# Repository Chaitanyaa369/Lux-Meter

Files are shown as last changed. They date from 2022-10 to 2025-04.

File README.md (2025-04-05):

💡 Lux Meter with ESP8266

This project is a web-based Lux Meter built using an ESP8266 microcontroller. It measures light intensity using a light sensor and displays the data graphically in real-time through a web interface. The design includes firmware, HTML/JS/CSS for visualization, and a custom-designed PCB.

📦 Project Structure

    Lux-Meter/
    │
    ├── Lux_meter/
    |    ├── Lux_meter.ino             # Firmware for ESP8266
    |    ├── index.html                # Web interface to visualize Lux data
    |    ├── style.css                 # Styling for the web interface
    │
    ├── Lux_Meter.sch             # Schematic file (Eagle)
    ├── Lux_Meter.brd             # PCB layout file (Eagle)
    ├── LM-Top.pdf                # PCB top view
    ├── LM-Bottom.pdf             # PCB bottom view
    ├── LM-C_name_value.pdf       # Component name/value placement
    ├── LM -components.pdf        # Components and connections
    │
    └── README.md                 # This file

🧠 Features

- Real-time Lux data visualization using Highcharts

- Simple Start/Stop/Reset buttons for live data streaming

- ESP8266-hosted web server

- Minimal and responsive interface

- Custom PCB design for compact integration

🔧 Hardware Used

- ESP8266 (ESP-12E/F)

- Light sensor (LDR or BH1750)

- LM1117-3.3V voltage regulator

- Capacitors: 100nF, 470pF, 47uF

- Resistors: 12K

- USB-to-Serial interface

- Misc: Connectors, header pins

You can view the hardware setup using:

- 📄 LM -components.pdf

- 🖼️ LM-Top.pdf and LM-Bottom.pdf

- 📐 LM-C_name_value.pdf

💻 Software Used

- Arduino IDE (for programming ESP8266)

- EAGLE CAD (for PCB design)

- HTML/CSS/JavaScript + Highcharts.js (for plotting)

🚀 Getting Started
Flash the Firmware:

1. Open Lux_meter.ino in Arduino IDE.

2. Install the ESP8266 board support (via Boards Manager).

3. Upload the sketch to the ESP8266.

Web Interface:

The ESP8266 serves the index.html and style.css from flash or SPIFFS.

- Open a browser to the ESP8266's IP address.

- The interface provides:

    - 📈 Real-time chart

    - ▶️ Start streaming

    - ⏹️ Stop streaming

    - 🔄 Reset the chart

PCB:

1. Open Lux_Meter.sch and Lux_Meter.brd in EAGLE.

2. Use the provided PDFs for a quick view of the design and component placement.

🌐 How It Works

- The ESP8266 reads Lux values periodically from the sensor.

- A lightweight web server handles HTTP requests to fetch data.

- The web interface uses JavaScript + Highcharts to plot values dynamically.

📄 License

MIT License. Portions of the web UI adapted from RandomNerdTutorials.
🙏 Acknowledgments

- Rui Santos (Random Nerd Tutorials) for the ESP8266 web interface inspiration

- Highcharts.js for charting library

- Eagle CAD for PCB design

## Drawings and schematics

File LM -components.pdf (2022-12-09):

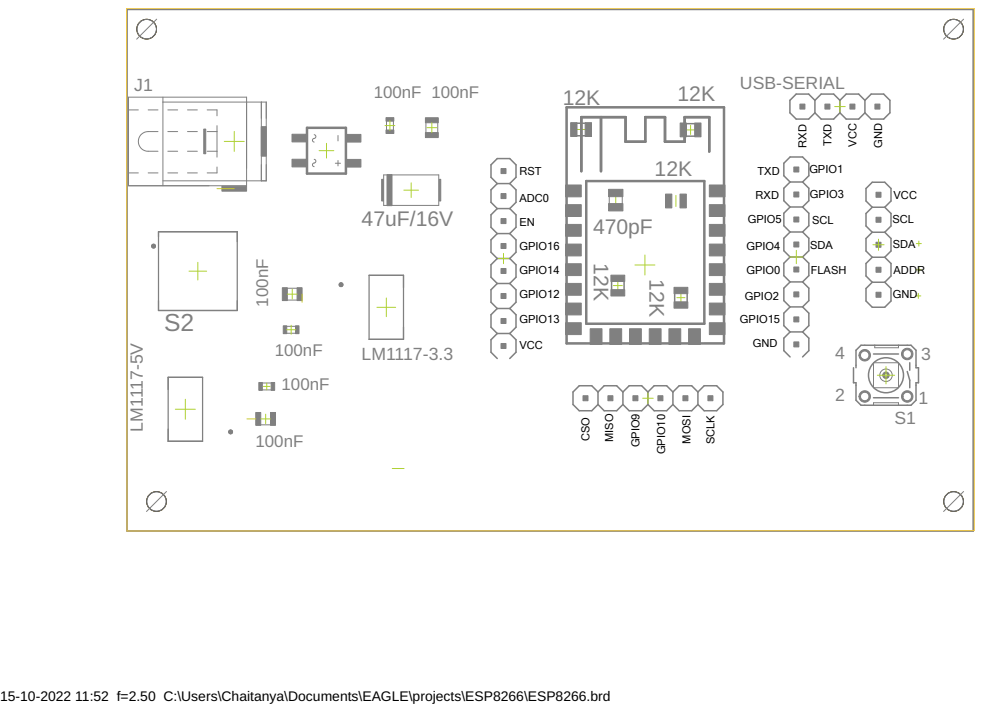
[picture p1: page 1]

15-10-2022 11:52 f=2.50 C:\Users\Chaitanya\Documents\EAGLE\projects\ESP8266\ESP8266.brd

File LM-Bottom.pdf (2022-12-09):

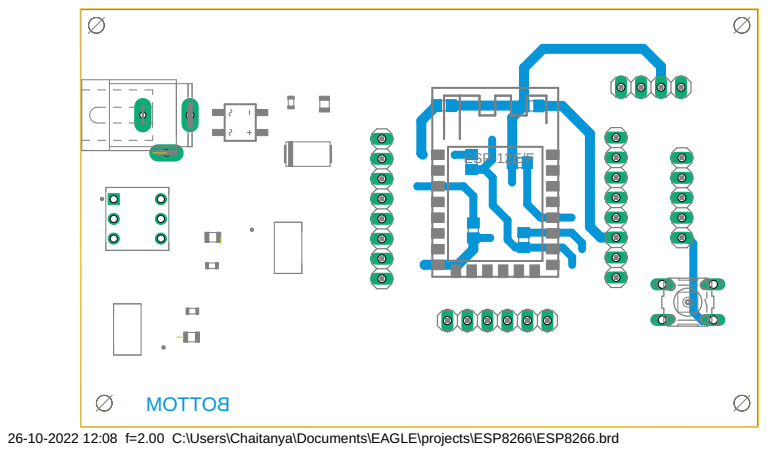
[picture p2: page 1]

26-10-2022 12:08 f=2.00 C:\Users\Chaitanya\Documents\EAGLE\projects\ESP8266\ESP8266.brd

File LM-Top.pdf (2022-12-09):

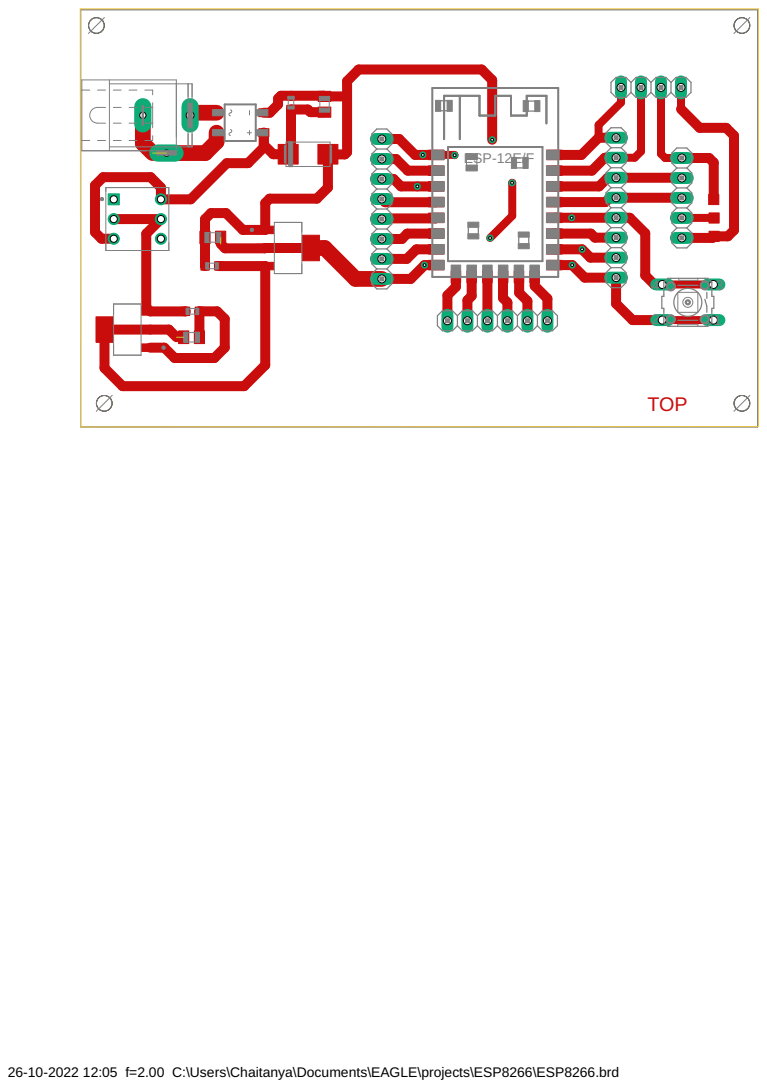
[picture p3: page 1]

26-10-2022 12:05 f=2.00 C:\Users\Chaitanya\Documents\EAGLE\projects\ESP8266\ESP8266.brd

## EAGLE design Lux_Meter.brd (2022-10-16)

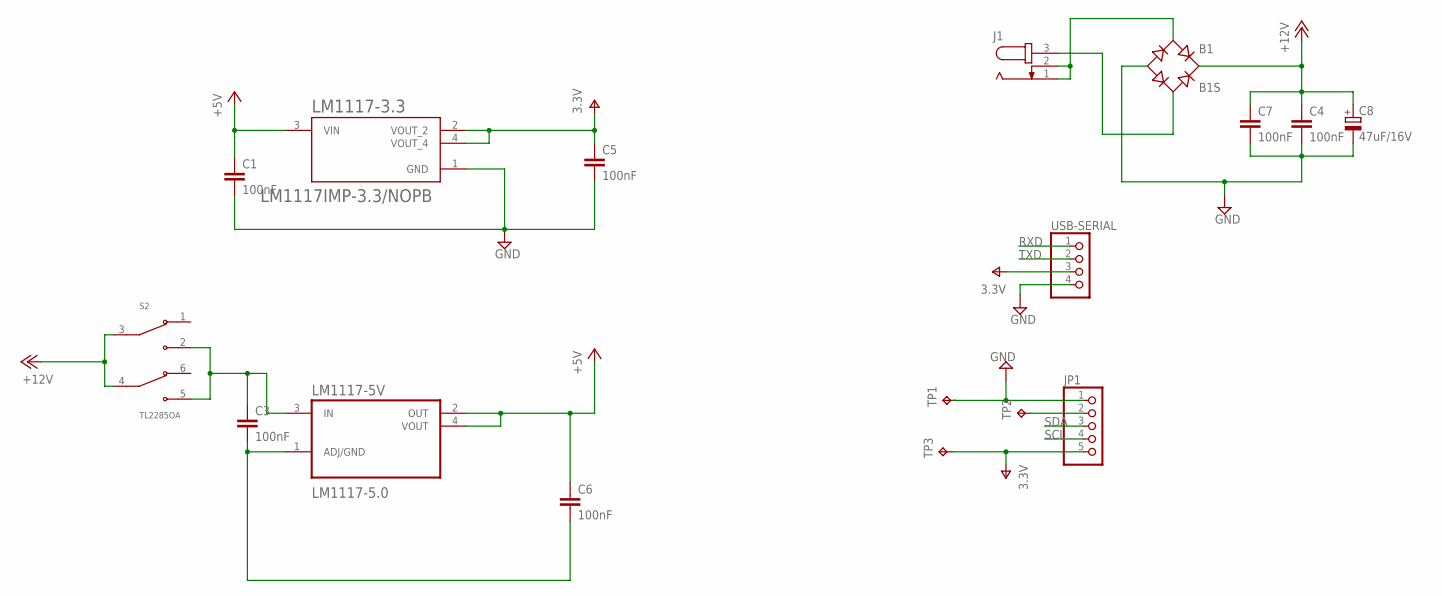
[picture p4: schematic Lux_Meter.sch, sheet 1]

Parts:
B1: B1S; MBS
C1, C3, C4: 100nF; C0603K
C5, C6, C7: 100nF; C0805K
C8: 47uF/16V; C/6032-28R
J1: JACK-PLUG0; SPC4077
JP1: PINHD-1X5; 1X05
LM1117-3.3: LM1117IMP-3.3/NOPB; VREG_LM1117IMP-3.3/NOPB
LM1117-5V: LM1117-5.0; SOT230P700X180-4N
S2: TL2285OA; SW_TL2285OA
TP1, TP2, TP3: TPTP13SQ; TP13SQ
USB-SERIAL: PINHD-1X4; 1X04

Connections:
+5V: C1.1, C6.1, LM1117-3.3.3 (VIN), LM1117-5V.2 (OUT), LM1117-5V.4 (VOUT)
+12V: B1.+, C4.1, C7.1, C8.+, S2.3 (COM1), S2.4 (COM2)
GND: B1.-, C1.2, C4.2, C5.2, C7.2, C8.-, JP1.1, LM1117-3.3.1 (GND), TP1.TP, USB-SERIAL.4; also elsewhere on the board
unnamed: B1.AC1, J1.1, J1.2
unnamed: B1.AC2, J1.3
unnamed: JP1.2, TP2.TP
unnamed: C3.2, C6.2, LM1117-5V.1 (ADJ/GND)
unnamed: C3.1, LM1117-5V.3 (IN), S2.2 (NO1), S2.5 (NO2)
RXD: USB-SERIAL.1; also elsewhere on the board
SCL: JP1.4; also elsewhere on the board
SDA: JP1.3; also elsewhere on the board
TXD: USB-SERIAL.2; also elsewhere on the board
V+: C5.1, JP1.5, LM1117-3.3.2 (VOUT_2), LM1117-3.3.4 (VOUT_4), TP3.TP, USB-SERIAL.3; also elsewhere on the board

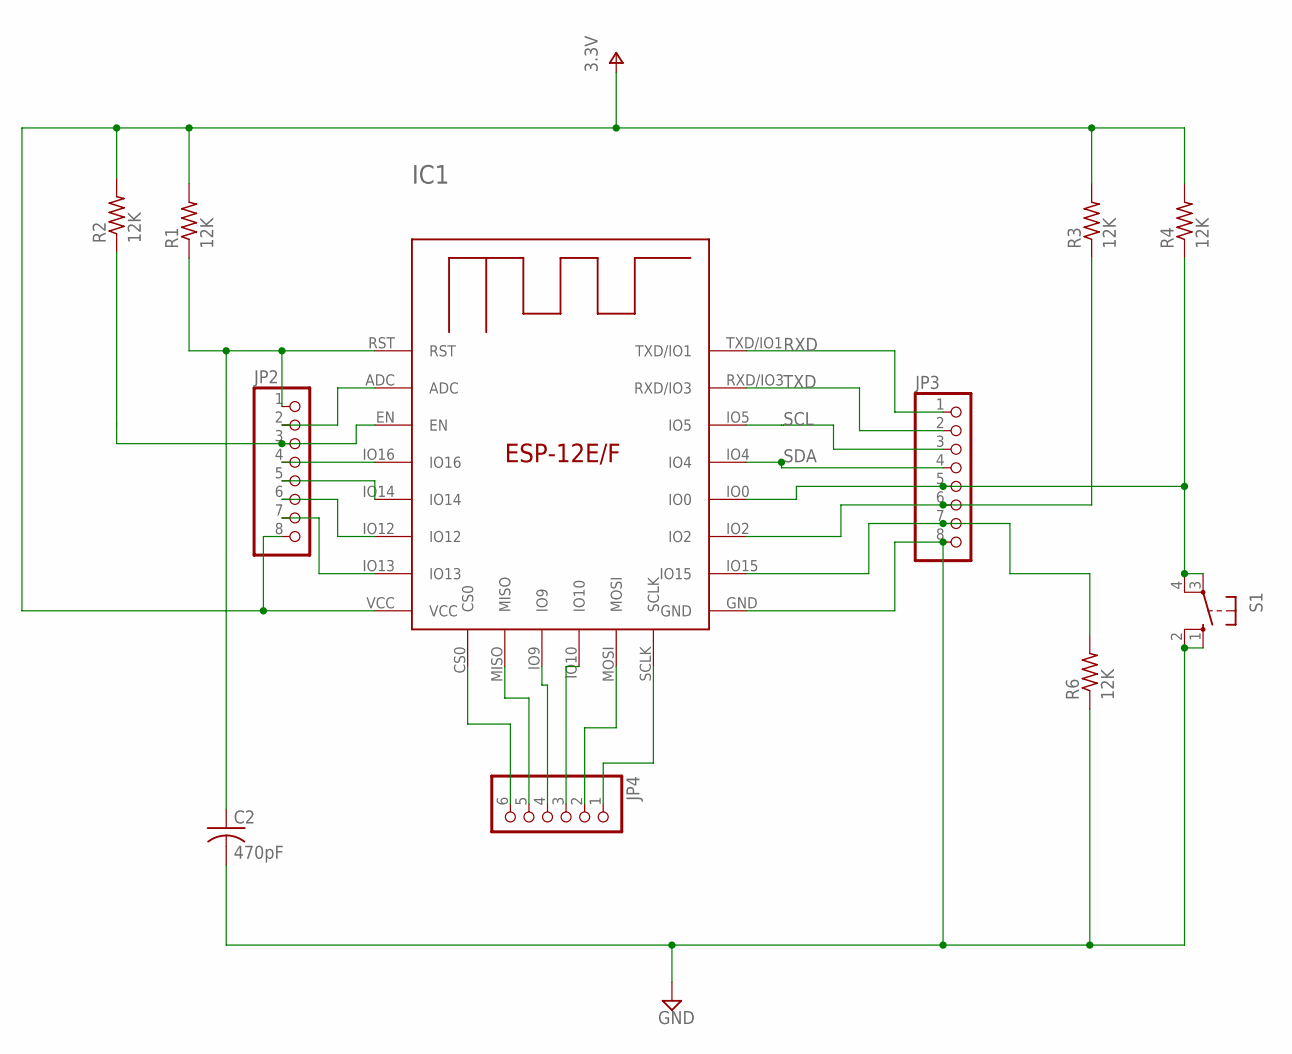
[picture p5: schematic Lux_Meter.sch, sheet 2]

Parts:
C2: 470pF; C0805
IC1: ESP-12E/F; ESP-12E
JP2, JP3: PINHD-1X8; 1X08
JP4: PINHD-1X6; 1X06
R1, R2, R3, R4, R6: 12K; R0805
S1: 10-XX; B3F-10XX

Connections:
GND: C2.2, IC1.GND, JP3.8, R6.1, S1.1 (S), S1.2 (S1); also elsewhere on the board
unnamed: C2.1, IC1.RST, JP2.1, R1.1
unnamed: IC1.IO15, JP3.7, R6.2
unnamed: IC1.IO0, JP3.5, R4.1, S1.3, S1.4 (P1)
unnamed: IC1.SCLK, JP4.1
unnamed: IC1.IO2, JP3.6, R3.1
unnamed: IC1.ADC, JP2.2
unnamed: IC1.EN, JP2.3, R2.1
unnamed: IC1.IO16, JP2.4
unnamed: IC1.IO14, JP2.5
unnamed: IC1.IO12, JP2.6
unnamed: IC1.IO13, JP2.7
unnamed: IC1.MOSI, JP4.2
unnamed: IC1.IO10, JP4.3
unnamed: IC1.IO9, JP4.4
unnamed: IC1.MISO, JP4.5
unnamed: IC1.CS0, JP4.6
RXD: IC1.TXD/IO1, JP3.1; also elsewhere on the board
SCL: IC1.IO5, JP3.3; also elsewhere on the board
SDA: IC1.IO4, JP3.4; also elsewhere on the board
TXD: IC1.RXD/IO3, JP3.2; also elsewhere on the board
V+: IC1.VCC, JP2.8, R1.2, R2.2, R3.2, R4.2; also elsewhere on the board

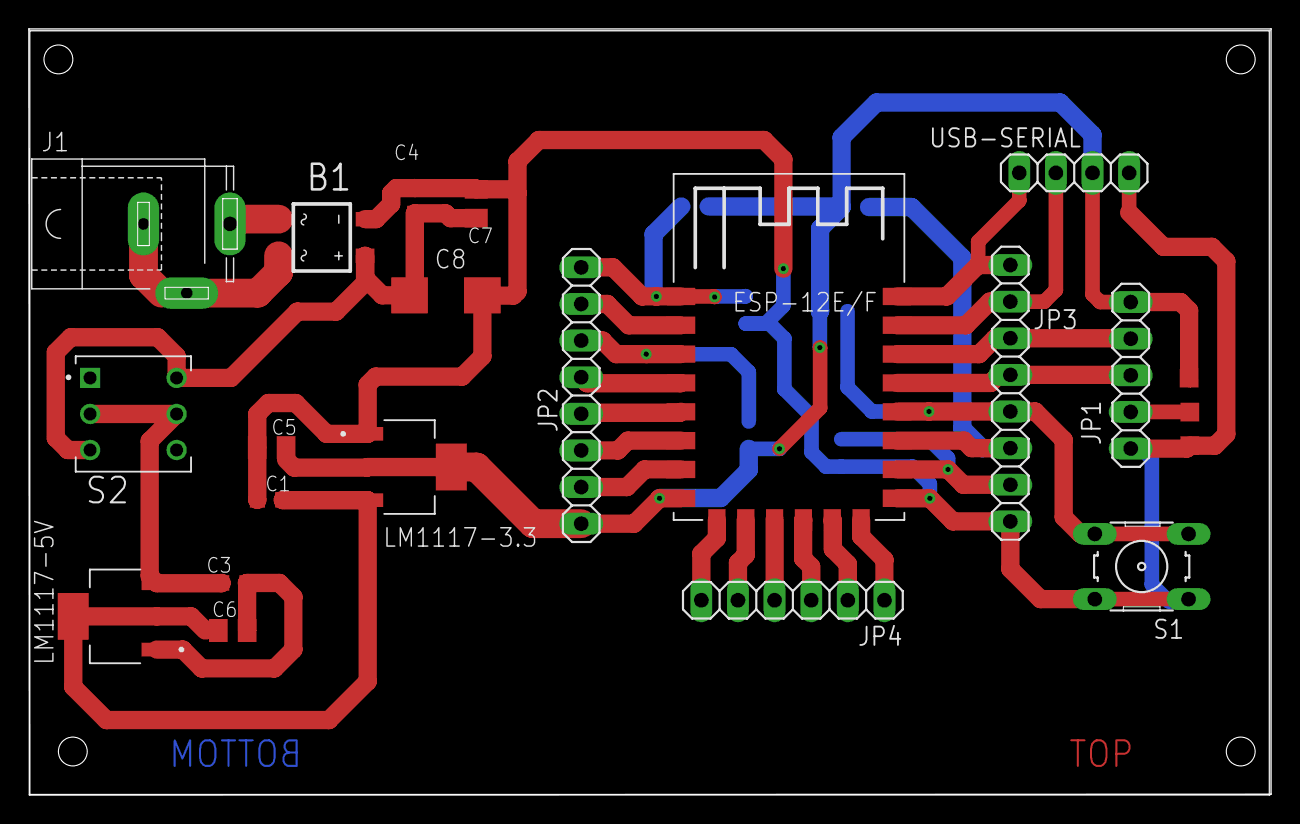
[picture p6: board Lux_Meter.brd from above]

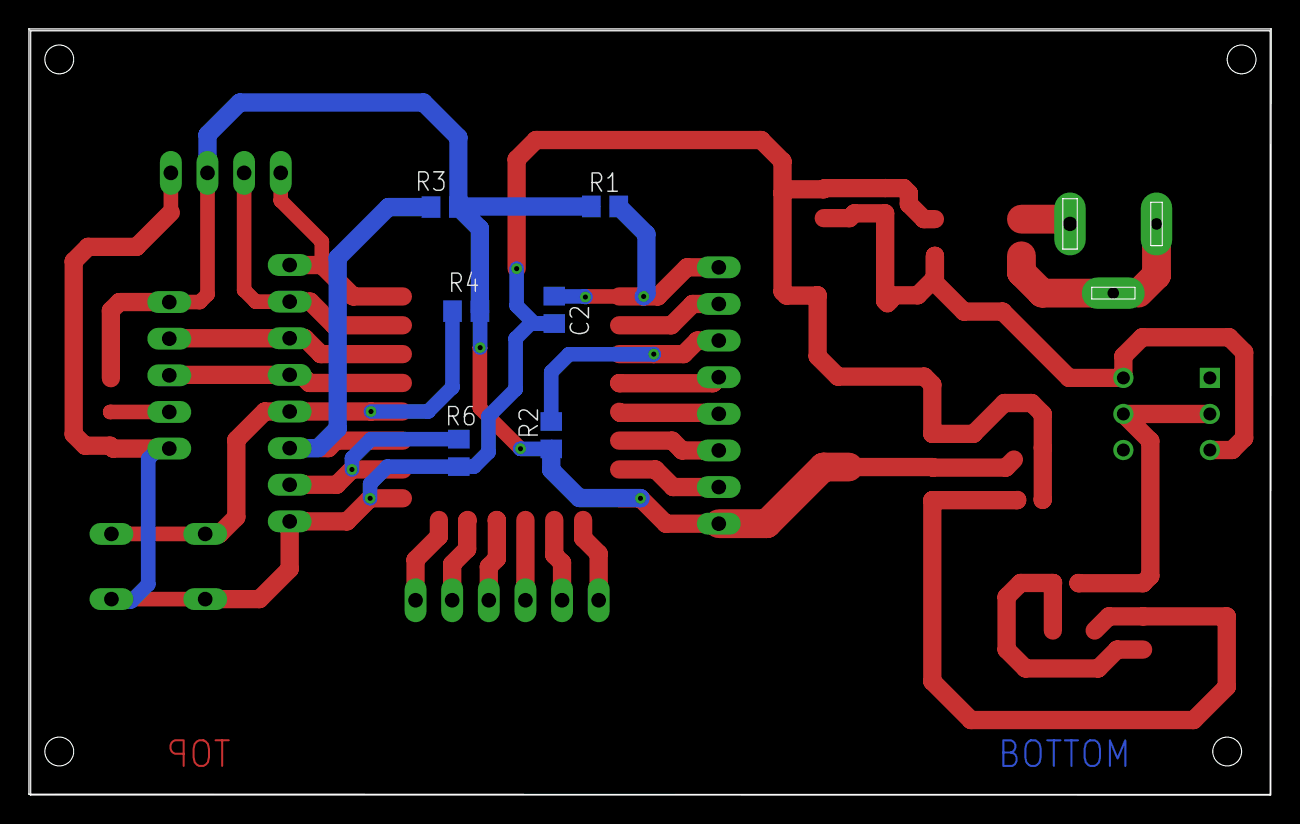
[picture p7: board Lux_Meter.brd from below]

Board: 2 copper layers, 86.2 x 53.1 mm, 28 parts (6 on the bottom side), 29 nets.

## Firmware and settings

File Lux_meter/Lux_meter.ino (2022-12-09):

#include <Arduino.h>
#include <ESP8266WiFi.h>
#include <Hash.h>
#include <ESPAsyncTCP.h>
#include <ESPAsyncWebServer.h>
#include <FS.h>
#include <LittleFS.h>
#include <EEPROM.h>
#include <Wire.h>
#include <BH1750.h>

BH1750 lightMeter;

//Variables
const int buttonPin = 2;
int i = 0;
int statusCode;
const char* ssid = "Default_SSID";
const char* passphrase = "Default_Password";
String st;
String content;

int led = 14;
float sensorMax;
int lastTime= 0;
float calibValue;

//Function Decalration
bool testWifi(void);
void launchWeb(void);
void setupAP(void);

// Create AsyncWebServer object on port 80
AsyncWebServer server(80);

bool testWifi(void);
void launchWeb(void);
void setupAP(void);
bool calibration();
String readLux();




void setup(){
  
  // Serial port for debugging purposes
  Serial.begin(115200);
  //-----------------
  Serial.println("Disconnecting current wifi connection");
  WiFi.disconnect();
  EEPROM.begin(512); //Initialasing EEPROM
  delay(10);
  //---------------
  Wire.begin();

  pinMode(buttonPin,INPUT);
  pinMode(led, OUTPUT);
  
  bool status; 
  // default settings
  // (you can also pass in a Wire library object like &Wire2)
  status = lightMeter.begin();  
  if (!status) {
    Serial.println("Could not find a valid BH1750 sensor, check wiring!");
    while (1);
  }

  

  // Initialize LittleFS
  if(!LittleFS.begin()){
    Serial.println("An Error has occurred while mounting LittleFS");
    return;
  }

  //---------------------------------------- Read eeprom for ssid and pass
  Serial.println("Reading EEPROM ssid");

  String esid;
  for (int i = 0; i < 32; ++i)
  {
    esid += char(EEPROM.read(i));
  }
  Serial.println();
  Serial.print("SSID: ");
  Serial.println(esid);
  Serial.println("Reading EEPROM pass");

  String epass = "";
  for (int i = 32; i < 96; ++i)
  {
    epass += char(EEPROM.read(i));
  }
  Serial.print("PASS: ");
  Serial.println(epass);


  WiFi.begin(esid.c_str(), epass.c_str());
  if (testWifi())
  {
    Serial.println("Succesfully Connected!!!");
    // Print ESP8266 Local IP Address
  Serial.println(WiFi.localIP());
  
  // Route for root / web page
  /*server.on("/calib",HTTP_GET, [](AsyncWebServerRequest *request){
    sensorMax = calibration();
    request->send(200,"text/plain", "/index.html");
  });*/
  server.on("/", HTTP_GET, [](AsyncWebServerRequest *request){
    request->send(LittleFS, "/index.html");
  });
  server.on("/lux", HTTP_GET, [](AsyncWebServerRequest *request){
    request->send_P(200, "text/plain", readLux().c_str());
  });


  // Start server
  server.begin();
  }
  else
  {
    Serial.println("Turning the HotSpot On");
    launchWeb();
    setupAP();// Setup HotSpot
  }

  Serial.println();
  Serial.println("Waiting.");

  // Connect to Wi-Fi
  /* WiFi.begin(ssid, password);
  while (WiFi.status() != WL_CONNECTED) {
    delay(1000);
    Serial.println("Connecting to WiFi..");.
    
  }*/

  
}

//----------------------------------Loop
void loop(){
  //float lux = lightMeter.readLightLevel();
  //Serial.print("Light: ");
  //Serial.print(lux);
  //Serial.println(" lx");
  //delay(200);
if(digitalRead(buttonPin) == HIGH){
    calibration();
    Serial.println("Calibrated Value is:");
    Serial.println(sensorMax);
    
  }
  else{
    Serial.println("Intensity");
    Serial.println(readLux());
  }

  
}

String readLux() {
  // Read lux
  float t = lightMeter.readLightLevel();
  //if(calibration() == true){
  t = (t/sensorMax)*100;
  Serial.println(t);
  return String(t);
  //}
  //else{
    //return String(t);
  //}
  
}

//--------------Calibration
bool calibration(){
  float v;
  lastTime = millis();
  while(millis() - lastTime < 15000){
    v = lightMeter.readLightLevel();
    //Serial.println(".");
    if(v >sensorMax){
      sensorMax = v;
      Serial.println(sensorMax);
            
    }
    digitalWrite(led,HIGH);
  }
  return true;
}
//----------------------------------------------- Fuctions used for WiFi credentials saving and connecting to it which you do not need to change
bool testWifi(void)
{
  int c = 0;
  Serial.println("Waiting for Wifi to connect");
  while ( c < 20 ) {
    if (WiFi.status() == WL_CONNECTED)
    {
      return true;
    }
    delay(500);
    Serial.print("*");
    c++;
  }
  Serial.println("");
  Serial.println("Connect timed out, opening AP");
  return false;
}

void launchWeb()
{
  Serial.println("");
  if (WiFi.status() == WL_CONNECTED)
    Serial.println("WiFi connected");
  Serial.print("Local IP: ");
  Serial.println(WiFi.localIP());
  Serial.print("SoftAP IP: ");
  Serial.println(WiFi.softAPIP());
  createWebServer();
  // Start the server
  server.begin();
  Serial.println("Server started");
}

void setupAP(void)
{
  WiFi.mode(WIFI_STA);
  WiFi.disconnect();
  delay(100);
  int n = WiFi.scanNetworks();
  Serial.println("scan done");
  if (n == 0)
    Serial.println("no networks found");
  else
  {
    Serial.print(n);
    Serial.println(" networks found");
    for (int i = 0; i < n; ++i)
    {
      // Print SSID and RSSI for each network found
      Serial.print(i + 1);
      Serial.print(": ");
      Serial.print(WiFi.SSID(i));
      Serial.print(" (");
      Serial.print(WiFi.RSSI(i));
      Serial.print(")");
      Serial.println((WiFi.encryptionType(i) == ENC_TYPE_NONE) ? " " : "*");
      delay(10);
    }
  }
  Serial.println("");
  st = "<ol>";
  for (int i = 0; i < n; ++i)
  {
    // Print SSID and RSSI for each network found
    st += "<li>";
    st += WiFi.SSID(i);
    st += " (";
    st += WiFi.RSSI(i);

    st += ")";
    st += (WiFi.encryptionType(i) == ENC_TYPE_NONE) ? " " : "*";
    st += "</li>";
  }
  st += "</ol>";
  delay(100);
  WiFi.softAP("Lux Meter", "");
  Serial.println("Initializing_softap_for_wifi credentials_modification");
  launchWeb();
  Serial.println("over");
}

void createWebServer()
{
  {
    server.on("/", [](AsyncWebServerRequest *request) {

      IPAddress ip = WiFi.softAPIP();
      String ipStr = String(ip[0]) + '.' + String(ip[1]) + '.' + String(ip[2]) + '.' + String(ip[3]);
      content = "<!DOCTYPE HTML>\r\n<html>Welcome to Wifi Credentials Update page";
      content += "<form action=\"/scan\" method=\"POST\"><input type=\"submit\" value=\"scan\"></form>";
      content += ipStr;
      content += "<p>";
      content += st;
      content += "</p><form method='get' action='setting'><label>SSID: </label><input type='text' name='ssid' length=32>";
      content += "<label>Password: </label><input type='password' name='pass' length=64>";
      content +="<input name = Submit' type='submit'></form>";
      content += "</html>";
      request->send(200, "text/html", content);
    });
    server.on("/scan", [](AsyncWebServerRequest *request) {
      //setupAP();
      IPAddress ip = WiFi.softAPIP();
      String ipStr = String(ip[0]) + '.' + String(ip[1]) + '.' + String(ip[2]) + '.' + String(ip[3]);

      content = "<!DOCTYPE HTML>\r\n<html>go back";
      request->send(200, "text/html", content);
    });

    server.on("/setting", [](AsyncWebServerRequest *request) {
      //AsyncWebParameter* p = request->getParam(i);
      String qsid = request->arg("ssid"); //p->name("ssid")
      String qpass = request->arg("pass");//p->name("pass")
      if (qsid.length() > 0 && qpass.length() > 0) {
        Serial.println("clearing eeprom");
        for (int i = 0; i < 96; ++i) {
          EEPROM.write(i, 0);
        }
        Serial.println(qsid);
        Serial.println("");
        Serial.println(qpass);
        Serial.println("");

        Serial.println("writing eeprom ssid:");
        for (int i = 0; i < qsid.length(); ++i)
        {
          EEPROM.write(i, qsid[i]);
          Serial.print("Wrote: ");
          Serial.println(qsid[i]);
        }
        Serial.println("writing eeprom pass:");
        for (int i = 0; i < qpass.length(); ++i)
        {
          EEPROM.write(32 + i, qpass[i]);
          Serial.print("Wrote: ");
          Serial.println(qpass[i]);
        }
        EEPROM.commit();

        content = "{\"Success\":\"saved to eeprom... reset to boot into new wifi\"}";
        statusCode = 200;
        ESP.reset();
      } else {
        content = "{\"Error\":\"404 not found\"}";
        statusCode = 404;
        Serial.println("Sending 404");
      }
      AsyncWebServerResponse *response = request->beginResponse(200, "text/plain", "Ok");
      response ->addHeader("Access-Control-Allow-Origin", "*");
      request->send(statusCode, "application/json", content);

    });
  }
}

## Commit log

2022-10-16 initial commit; sch,brd and ino
    [Lux_Meter.brd, Lux_Meter.sch]
2022-12-09 added calibration and start, stop, reset
    [Lux_meter.ino]
